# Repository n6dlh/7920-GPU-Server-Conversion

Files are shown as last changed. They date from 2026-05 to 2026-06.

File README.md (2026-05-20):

# 7920-GPU-Server-Conversion

This is the collection of materials and how to convert the Dell Precision T7920 to a server to run not only multiple GPUs, but to run older and cheaper Nvidia Data Center GPU for use of doing local LLM, Agentic Machine Learning, hosting, CFD analysis using GPUs. 

This will concentrate on the things I had to do, build, and modify to allow me to use these server Nvidia P100 GPUs in a work station that was not designed for them. The changes to the card to enable the Dell Bios to see them, cooling solutions that is automated and tuneable, the mods to the computer to get them to fit and have the correct front to back airflow. 

I started this wit a Base Dell Precision T7920 workstation that had a single Xeon Bronze CPU and 8GB of ram. To Dual Xeon 6136 Gold proccessors with 64gb of ram and gorwing. Running Proxmox on an NVME boot drive with 2x Nvidia P100 GPUs with 16GB of Vram each, and a 3rd card going in. 

The Basic Overview is I modified the internal air deflector to keep the CPU, Ram, and Vram air guide with a 3d printed part, used 2 4020 Arctic server 40mm fans per GPU with an 3d printed fan duct. Dallas temp sensors, and an ESP32 to monitor the temps, and control the fan PWM and Tach signals using ESP Home and home assistant. The power for the fans and ESP32 use a Dell PCIE single plug power cable that came with the workstation. 

Powering the GPU I purchased custom Nvidia P100 8 pin to dual 8pin PCIe power plugs, and custom Dell 10 pin power rail to to dual 8 pin PCIe plugs to split the current accross 2 wires instead on just 1. 

The 7920 has 4 power rail 10 pin plugs capable of 300w each in power delivery, a 1450w power supply, and can take Dual Xeon Gen 1 & Gen 2 processors and up to 3Tb of EEC DDR4 ram. 

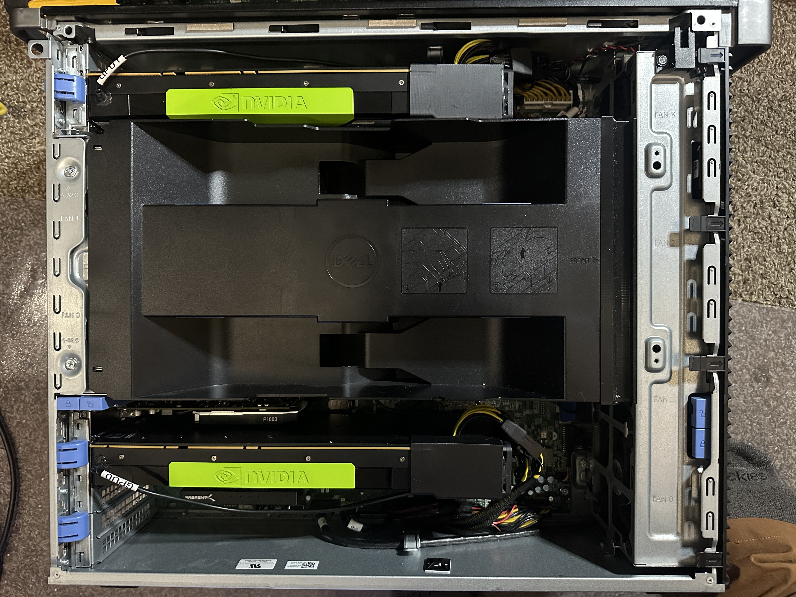
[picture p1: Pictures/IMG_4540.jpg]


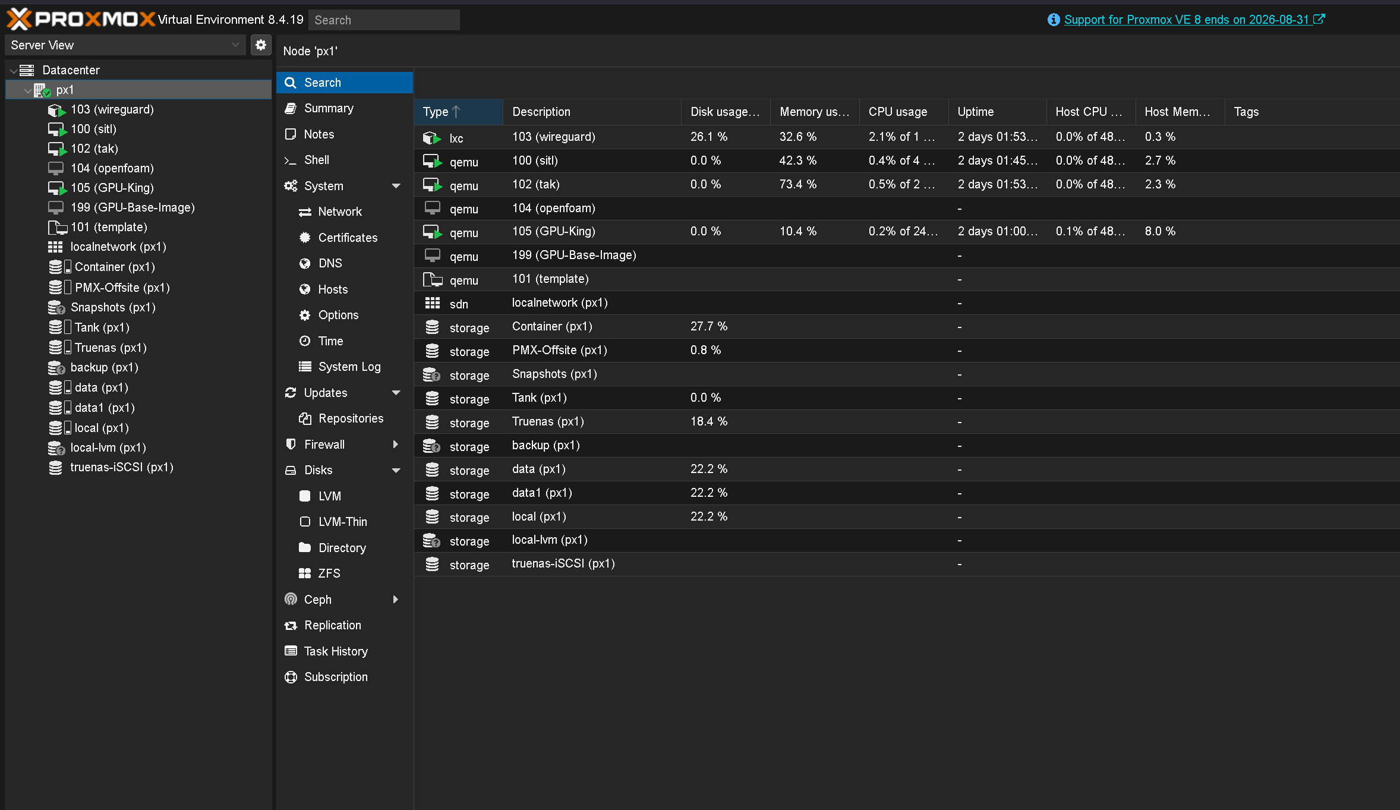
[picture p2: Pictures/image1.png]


I am running Proxmox on the machine,and passing the Nvidia GPU to a VM. In the VM I have ollama.cpp running with Open Webui and Hermes agent running. I also have the Hermes Telegram plugin running 

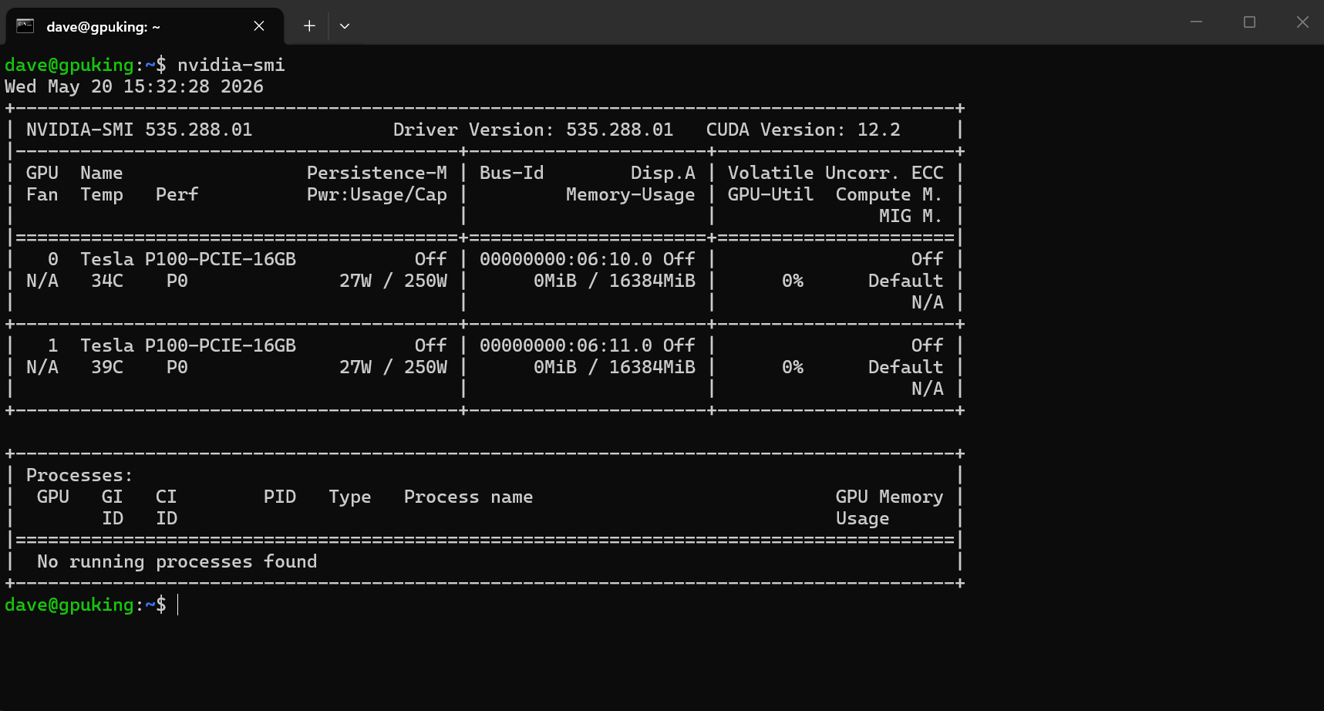
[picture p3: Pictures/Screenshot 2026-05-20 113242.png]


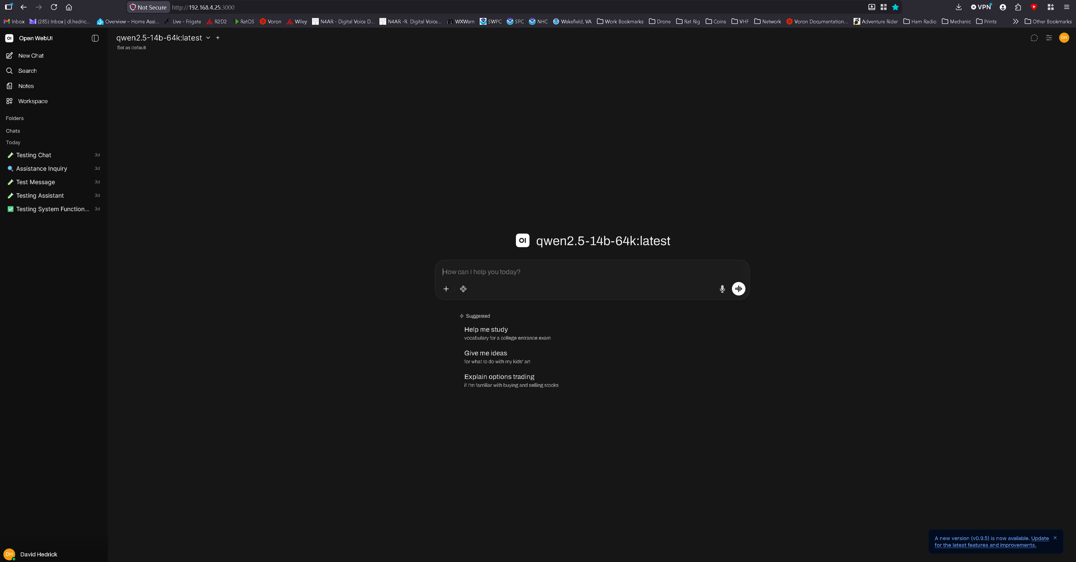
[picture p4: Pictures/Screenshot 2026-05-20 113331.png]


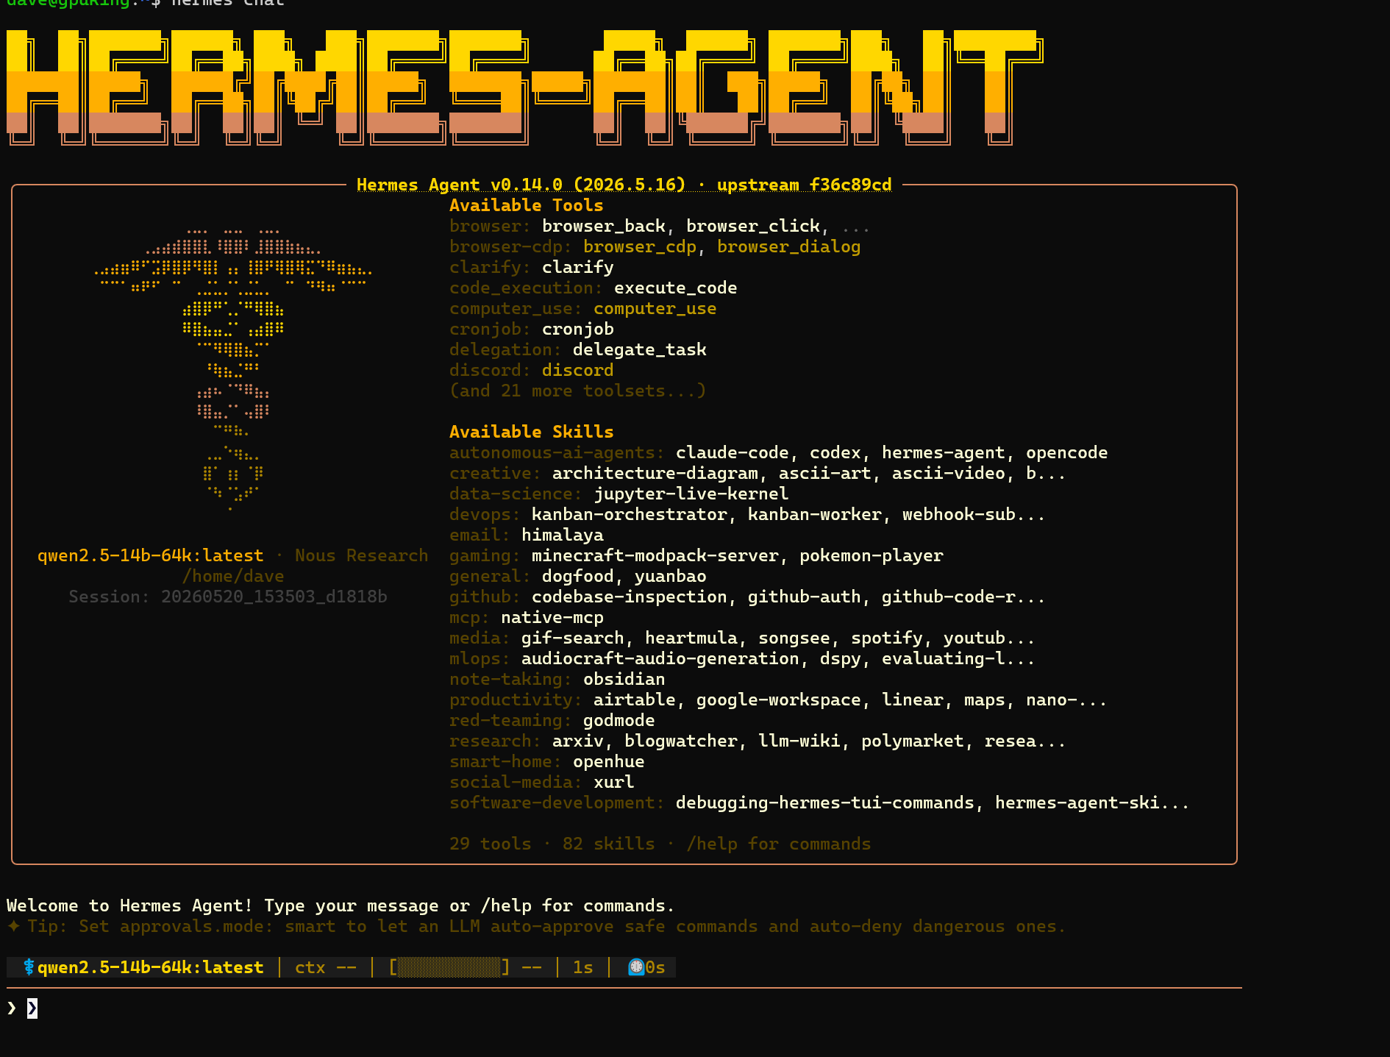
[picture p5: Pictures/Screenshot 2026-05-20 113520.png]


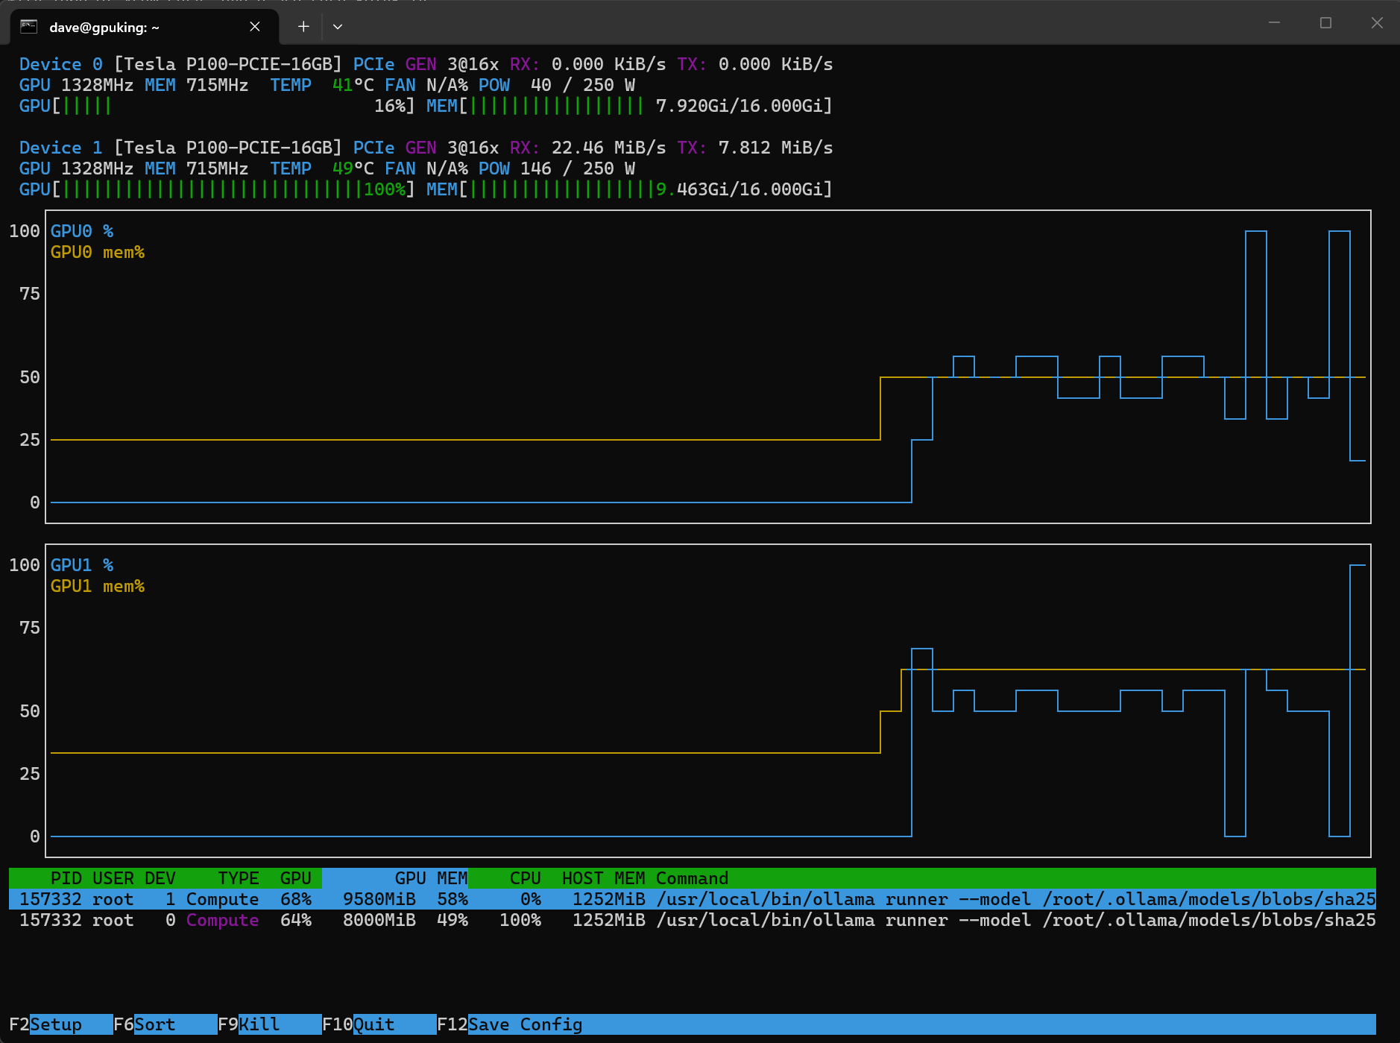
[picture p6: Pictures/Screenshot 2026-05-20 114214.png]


This is an NVTOP running qwen2.5-14b queried in Open Web UI and loading the model to memory and answering, I have it set to unload the model when it has not been queried in a minute, this is able to spread the model over the Vram of multiple GPUs and works very well. 

One of the biggest challenges to getting the Dell Bios to see the cards at all and getting it to boot. Throwing the card in and powering on will not work. The Bar address of the PCIE on these cards are huge. For the dell you have to enable read addresses over 4GB on the PCIE and shut off some of the Intel PCIE setting. Also you will need a windows computer that can boot with the cards and see them. Download [NVflash from GPUZ](https://www.techpowerup.com/download/nvidia-nvflash/) and make sure that the card is being seen by the computer. Unzip the folder and then open a command prompt as Adminastrater. Move into the folder where the NVflash64 file is and backup the flash. When in command prompt run nvflash64 --save backupbios.rom

Once that is done run the command

nvflash64 --listgpumodes

It should come back showing Compute if that is the case you will need to set it to display mode, this only changes the how the bios sees the card, it does not limit the ability to use the vram, it will set the bar size to 256mb for the boot portion, once the driver loads the card will be able to be fully utilized. 

run this

nvflash64 --gpumode graphics 

If that completes without errors you can run the list mode again to validate the graphics is enabled. 

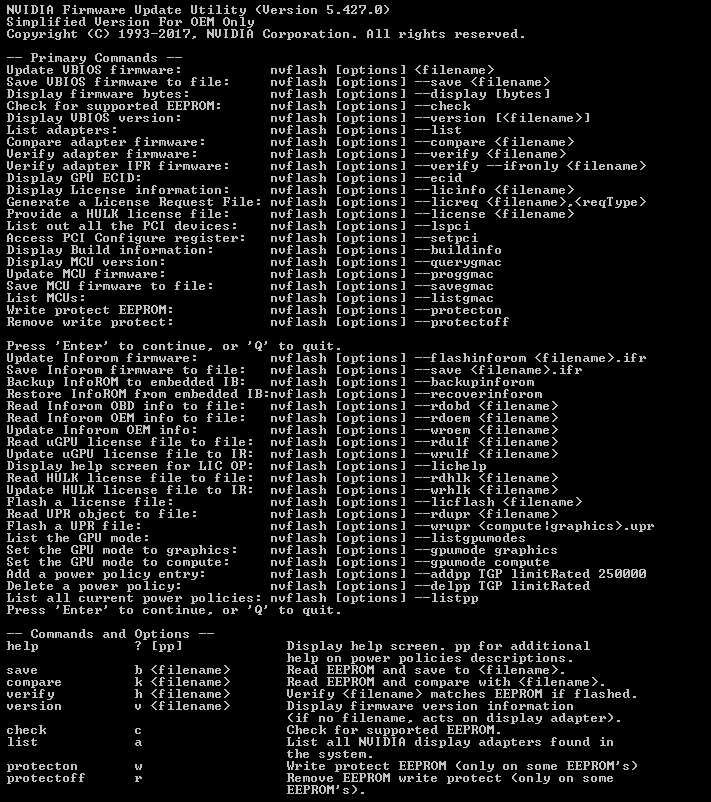
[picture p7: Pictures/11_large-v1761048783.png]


The next challenge is keeping the Proxmox driver from loading so you can pass the gpu through to the VM. I will touch on that in the future, I have to go through setting that up again, but there are videos on how to set it up. Next is in the VM you have to download the Nvidia 535 driver, tools, adn Cuda to get it all working.

One thing to keep in mind is there is only 4 X16 PCIe lanes in the T7920. For a single CPU slot 2&4 are the X16 Slots. If using 2 cpus you can use slots 6&7 as X16 slots. In the end with this I am using slots 2 and 7 currently, and plan to add another P100 to slot 4. I already have it and just need to change the code to the ESP and drop it in.

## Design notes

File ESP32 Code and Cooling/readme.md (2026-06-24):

This code is setup for ESP Home to run on home assistant and can be vide coded to use as a standard ESP32 using IDE. 

The updated code will scale up to 3 GPU, it will use the Gpu_bank.yaml to pull the information in when compiling. Use Studio Code Server on HAOS and drop the files into the ESPhome folder. You will see the new files in the ESP Home on HAOS. Use the initial flash to the ESP to copy the encryution and password information, and pull the dallas sensor addresses from the logs off the initial flash, then validate the code. 

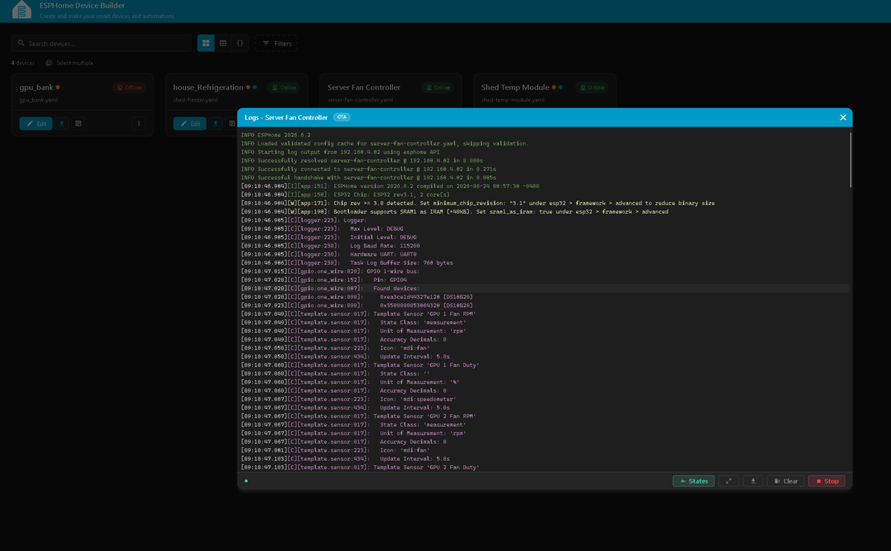
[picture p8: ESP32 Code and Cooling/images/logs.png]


This has its own webpage and then integrades into HAOS, and was programmed and setup on ESPhome plugin on HAOS!
ESP Home main page. 

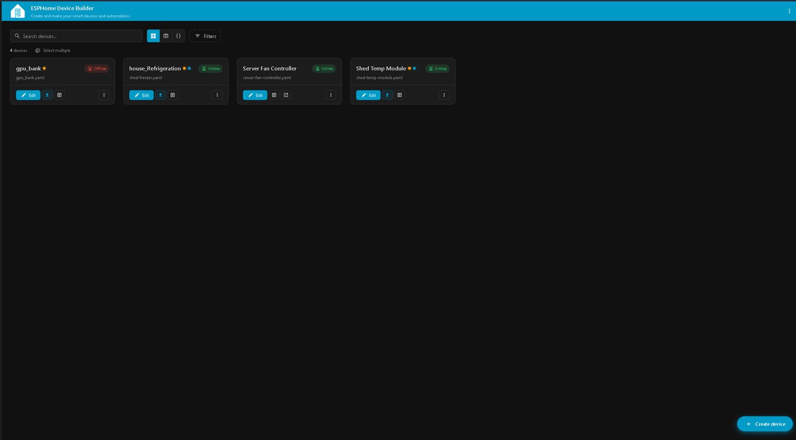
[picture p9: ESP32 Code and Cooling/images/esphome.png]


Fan controller added to HAOS dashboard

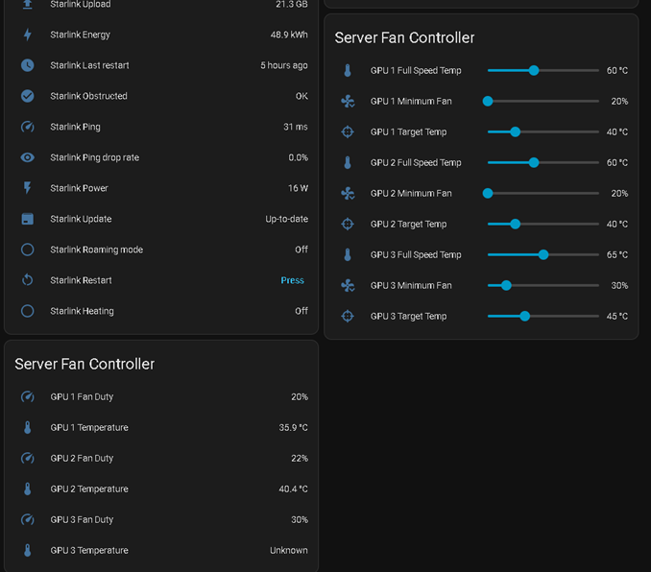
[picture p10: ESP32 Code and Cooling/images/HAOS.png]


Diagnostics information dahboard panel

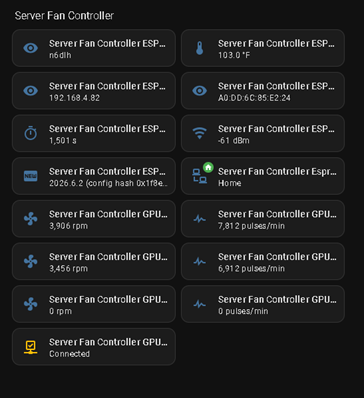
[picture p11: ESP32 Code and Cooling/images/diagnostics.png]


Here is the webpage:

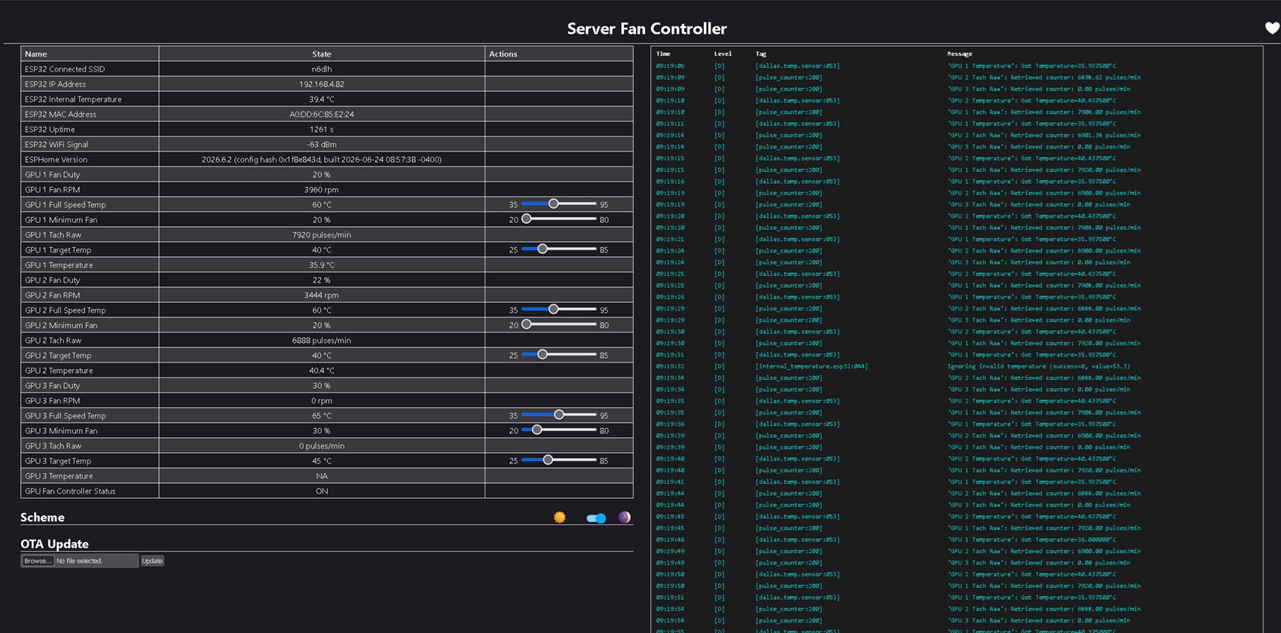
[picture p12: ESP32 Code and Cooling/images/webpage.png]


The logs show in real time and can also be checked in ESPhome, supports OTA updates and programming once it is programmed over USB. 
The Dallas sensors are single pin addressed, so that will need to be set for each fan bank. An initial base program is done to setup the ESPhome and the first part of the code
that enables the one pin. Once its programmed you can pull the logs and find the addresses of the sensors and add that to the code plus your SSID, and password, and encryption. 

For the fans and powering the ESP32 I picked up this https://www.amazon.com/dp/B0B2L68WSZ?ref_=ppx_hzsearch_conn_dt_b_fed_asin_title_7&th=1 PCie to 6 fan output and a kit to feed the tach and PWM to the ESP32 https://www.amazon.com/dp/B0F4JM3B7K?ref_=ppx_hzsearch_conn_dt_b_fed_asin_title_12

The trick here is to only use one of the fan tachs from each fan pair, and run each PWM to each fan. So in the end the server fans per GPU will have a fan with 3 wires, and one with 4 wires going to it. 
For the fans I used Arctic 1400-15000 RPM PWM 4 wire server 4028 fans. These fans can be loud, that is why I made this controller. It also has the added benifit that if the ESP fails or locks up and there it a loss of PWM the fans will default to full speed. https://www.amazon.com/dp/B09SB9D7V2?ref_=ppx_hzsearch_conn_dt_b_fed_asin_title_17&th=1

For the GPU power I used this adapter https://www.amazon.com/dp/B0BM7HT56K?ref=ppx_yo2ov_dt_b_fed_asin_title&th=1 and this https://www.amazon.com/dp/B07HCYDK5K?ref=ppx_yo2ov_dt_b_fed_asin_title&th=1

For the ESP32 I used a standard ESP on a dev board https://www.amazon.com/dp/B0C8H6ZGRR?ref_=ppx_hzsearch_conn_dt_b_fed_asin_title_37&th=1 and standard dupont connector for all of the connection that allow Power, Ground, and signal wires, and a barrel connection to the ESP for power. I used the pin kit above to adapt one of the 12v fan connections to the 5.5x2.4mm barrel connections. The Dev board has an on board voltage regulator. I used PCB sticky mounts, and slightly drilled the dev board out and stuck them to the backplance side of the Dell below the power rail PCB. The Dallas sensor 4.7k ohm resistors are in the wiring. 

For the PWM and Tach signals I made a breadboard for them and 3D printed a case for it. I used this to add the dropping resistors and the capacitors for noise. 

The 3D printed fan mount I used for the P100 is located here. https://www.printables.com/model/100708-p100-40mm-fan-mount/files
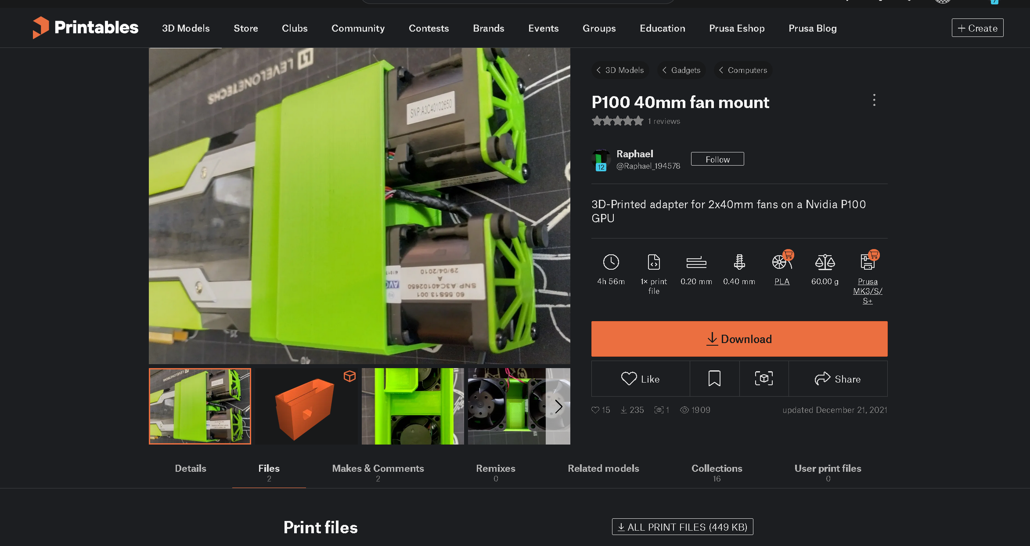
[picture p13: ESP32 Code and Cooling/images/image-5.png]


The designer used quad fans but they are overkill with the controller I made. It allows you to set the fan ramping PID loop to whatever you need to keep them cool, I have run them very hard and since setting the PID loop they never get over 55C.

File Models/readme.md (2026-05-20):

I will have a link soon to Printables that will link back here for the entire build. I have uploaded the STL file and the 3mf in case anyone wants to make changes, if you make some cool changes hit me up and let me know, would be happy to add anything here an link to your repo and printables

https://www.printables.com/model/1727840-dell-precision-tower-t7920-fan-shroud-for-long-gpu

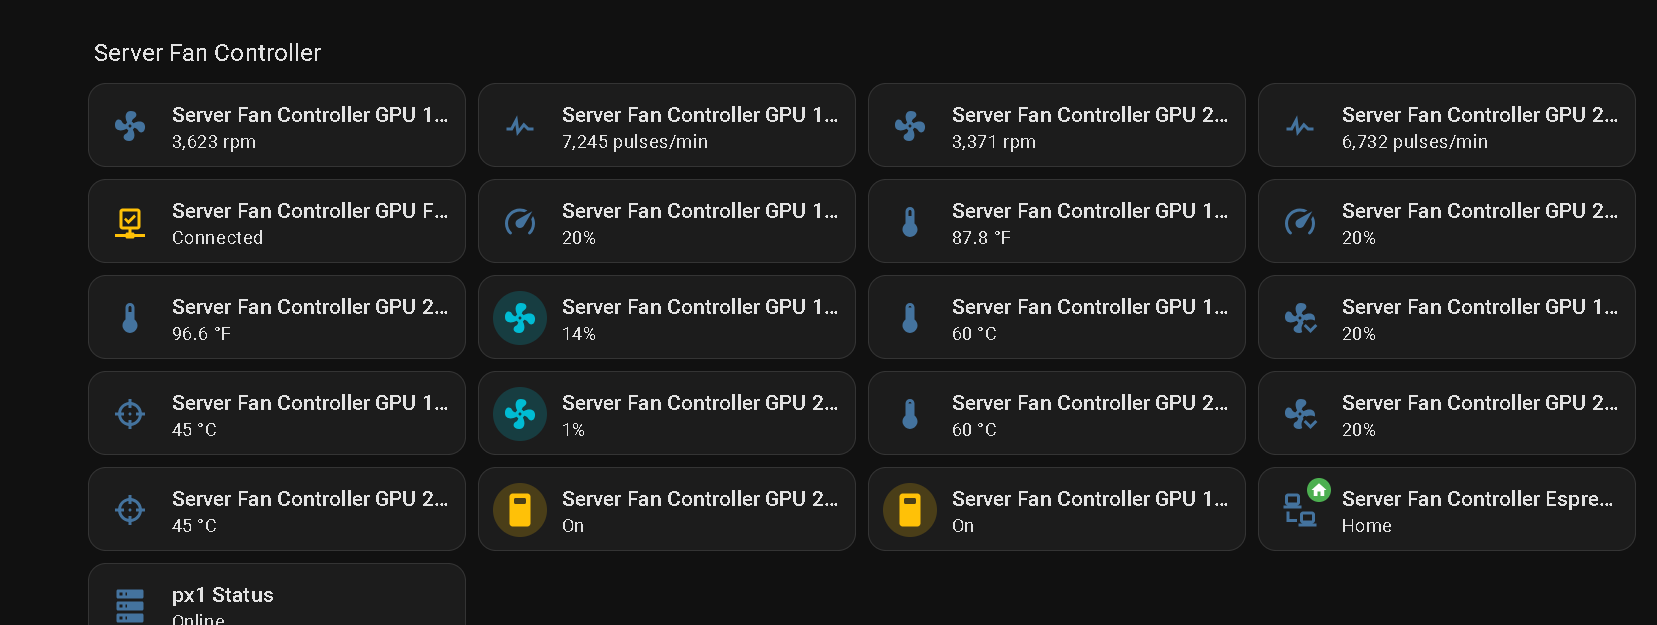
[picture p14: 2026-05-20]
ESP32 Code and Cooling/images/image.png

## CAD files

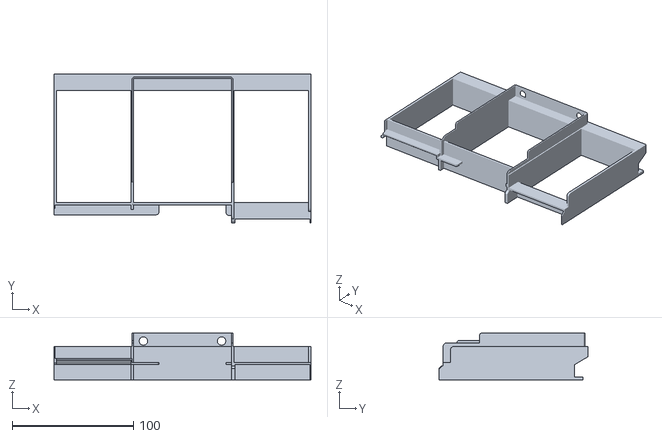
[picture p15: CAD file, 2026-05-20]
Models/Air Duct V1 v3.stl
212.0 x 122.7 x 38.5

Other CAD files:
Models/Air Duct V3.3mf

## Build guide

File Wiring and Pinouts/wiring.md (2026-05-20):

| Function | GPIO |
| --- | --- |
| 1-Wire (Dallas) | GPIO4  |
| Fan Bank 1 PWM  | GPIO18 |
| Fan Bank 2 PWM  | GPIO19 |
| Fan Bank 1 Tach | GPIO25 |
| Fan Bank 2 Tach | GPIO26 |

Components:
2x DS18B20
1x 4.7kΩ resistor
Wiring:
ESP32 GPIO4 ─────┬──────── Sensor 1 Data
                 └──────── Sensor 2 Data

GPIO4 ──[4.7kΩ]── 3.3V

All sensors:
- VCC → 3.3V
- GND → GND

| Wire | Function |
| --- | --- |
| Black  | GND |
| Yellow | +12V |
| Green  | Tach |
| Blue | PWM |

12V PSU (+) ────── all fan yellow wires
12V PSU (GND) ──── ESP32 GND + fan grounds

GPIO18 ─────┬──── Fan1 PWM (blue)
            └──── Fan2 PWM (blue)

GPIO19 ─────┬──── Fan3 PWM (blue)
            └──── Fan4 PWM (blue)  
Fan1 Tach (green) ─── GPIO25

Fan2 Tach (green) ─── GPIO26

GPIO25 ──[10kΩ]── 3.3V
GPIO26 ──[10kΩ]── 3.3V

Tach line ──[1kΩ]── GPIO
               |
              100nF
               |
              GND

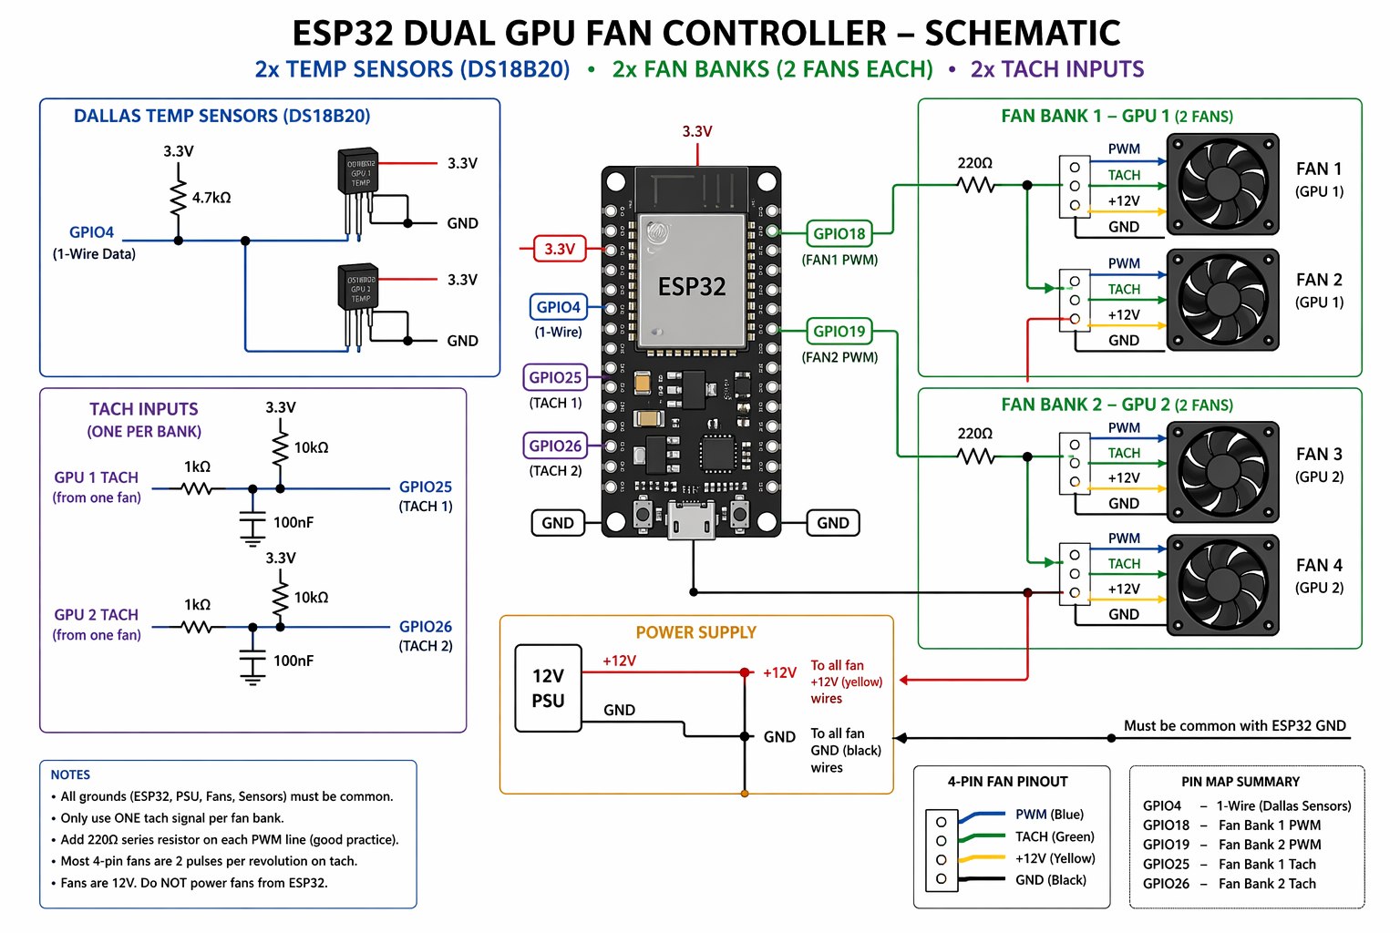
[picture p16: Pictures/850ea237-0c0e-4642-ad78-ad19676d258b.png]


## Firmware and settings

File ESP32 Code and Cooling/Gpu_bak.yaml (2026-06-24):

# ---------------------------------------------------------------
# Reusable per-GPU fan bank.
# Included once per GPU from the main config via packages + vars.
# Every id/name is templated off ${gpu_id} / ${gpu_name} so the
# three instances never collide.
# ---------------------------------------------------------------

substitutions:
  # Defaults (overridden by vars: in the main file's package include)
  gpu_id: gpu1
  gpu_name: "GPU 1"
  pwm_pin: GPIO18
  tach_pin: GPIO25
  temp_address: "0x0000000000000000"

sensor:
  # ---- DS18B20 temp on the shared 1-Wire bus (bus is defined in main) ----
  - platform: dallas_temp
    address: ${temp_address}
    name: "${gpu_name} Temperature"
    id: ${gpu_id}_temp
    update_interval: 5s
    device_class: temperature
    state_class: measurement
    unit_of_measurement: "°C"

  # ---- Tach: read ONE fan per bank. 100us filter rejects noise. ----
  # HW NOTE: prefer an external 10k pull-up to 3.3V (NOT 12V) on this line.
  - platform: pulse_counter
    pin:
      number: ${tach_pin}
      mode:
        input: true
        pullup: true
    name: "${gpu_name} Tach Raw"
    id: ${gpu_id}_tach_raw
    update_interval: 5s
    unit_of_measurement: "pulses/min"
    accuracy_decimals: 0
    entity_category: diagnostic
    internal_filter: 100us
    count_mode:
      rising_edge: INCREMENT
      falling_edge: DISABLE

  # ---- RPM (2 pulses/rev) ----
  - platform: template
    name: "${gpu_name} Fan RPM"
    id: ${gpu_id}_rpm
    lambda: 'return id(${gpu_id}_tach_raw).state / 2.0;'
    update_interval: 5s
    unit_of_measurement: "rpm"
    accuracy_decimals: 0
    icon: mdi:fan
    state_class: measurement
    entity_category: diagnostic

  # ---- Duty % for HA display ----
  - platform: template
    name: "${gpu_name} Fan Duty"
    id: ${gpu_id}_duty_pct
    lambda: 'return id(${gpu_id}_last_speed) * 100.0;'
    update_interval: 5s
    unit_of_measurement: "%"
    accuracy_decimals: 0
    icon: mdi:speedometer

# ---- 25kHz PWM output, driven directly by the control loop ----
output:
  - platform: ledc
    pin: ${pwm_pin}
    id: ${gpu_id}_pwm
    frequency: 25000 Hz

# ---- Tuning controls ----
number:
  - platform: template
    name: "${gpu_name} Target Temp"
    id: ${gpu_id}_target_temp
    min_value: 25
    max_value: 85
    step: 1
    initial_value: 45
    optimistic: true
    restore_value: true
    unit_of_measurement: "°C"
    icon: mdi:target

  - platform: template
    name: "${gpu_name} Minimum Fan"
    id: ${gpu_id}_min_speed
    min_value: 20
    max_value: 80
    step: 1
    initial_value: 30
    optimistic: true
    restore_value: true
    unit_of_measurement: "%"
    icon: mdi:fan-chevron-down

  - platform: template
    name: "${gpu_name} Full Speed Temp"
    id: ${gpu_id}_full_temp
    min_value: 35
    max_value: 95
    step: 1
    initial_value: 65
    optimistic: true
    restore_value: true
    unit_of_measurement: "°C"
    icon: mdi:thermometer-high

globals:
  - id: ${gpu_id}_last_speed
    type: float
    restore_value: no
    initial_value: '0.30'

# ---- Control loop: always on (no auto switch). NaN temp -> min speed. ----
interval:
  - interval: 5s
    then:
      - lambda: |-
          float temp      = id(${gpu_id}_temp).state;
          float target    = id(${gpu_id}_target_temp).state;
          float full_temp = id(${gpu_id}_full_temp).state;
          float min_speed = id(${gpu_id}_min_speed).state / 100.0f;
          float s;
          if (isnan(temp)) {
            s = min_speed;                      // sensor missing/disconnected
          } else {
            if (full_temp <= target) full_temp = target + 5.0f;
            if (temp <= target) {
              s = min_speed;
            } else if (temp >= full_temp) {
              s = 1.0f;
            } else {
              float ratio = (temp - target) / (full_temp - target);
              s = min_speed + ratio * (1.0f - min_speed);
            }
          }
          id(${gpu_id}_last_speed) = s;
          id(${gpu_id}_pwm).set_level(s);

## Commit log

2026-05-20 Second Commit
    [Air Duct V1 v3.stl, Air Duct V3.3mf]
2026-06-24 Updated to new code base for up to 3 fans, and eliminated the off switch and feednack loop fight in the code to 3 gpu. Also added a picture of pulling logs on new ESP home for dallas sensor addressin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
    [Server_fan_controller.yaml]
